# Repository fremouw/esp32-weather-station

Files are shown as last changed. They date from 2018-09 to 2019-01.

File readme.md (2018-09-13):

# ESP32 Weather Station

[ESP32](https://www.espressif.com/en/products/hardware/esp32/overview) based weather station. It shows four screens. 1) Current time and date (synced over NTP) 2) The current (local) weather conditions (data from the Weather underground) 3) 3-day forecast (also with data from the weather underground) 4) Current temperature, humidity, air pressure and, air quality (eCO2 and TVOC). This project was once based on https://github.com/squix78/esp8266-weather-station-platformio-demo, but most of it probably 90% is rewritten and targeted for the ESP32.

## Demo
(http://www.youtube.com/watch?v=XPXsWYJnScY "demo video")
## Software

Please see the config.example.h to configure your board.

## Hardware

My version uses a [2.42" OLED display](https://www.ebay.com/itm/SPI-2-42-OLED-128x64-Graphic-OLED-Module-Display-Arduino-PIC-AVR-Multi-wii/162156495387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) over SPI. A Bosch BME280 chip for measuring the temperature, humidity and air pressure. The SGP30 is used to measure the air quality, eCO2 (equivalent calculated carbon-dioxide) and TVOC (Total Volatile Organic Compound) concentration. Both these sensors are attached using a 4-wire molex connector, to keep some distance from the board and display; as these generate some heat which influences the sensors.

The ESP32 board used is a DOIT ESP32 Devkit v1, you can find these on ebay.

### Schematic and board

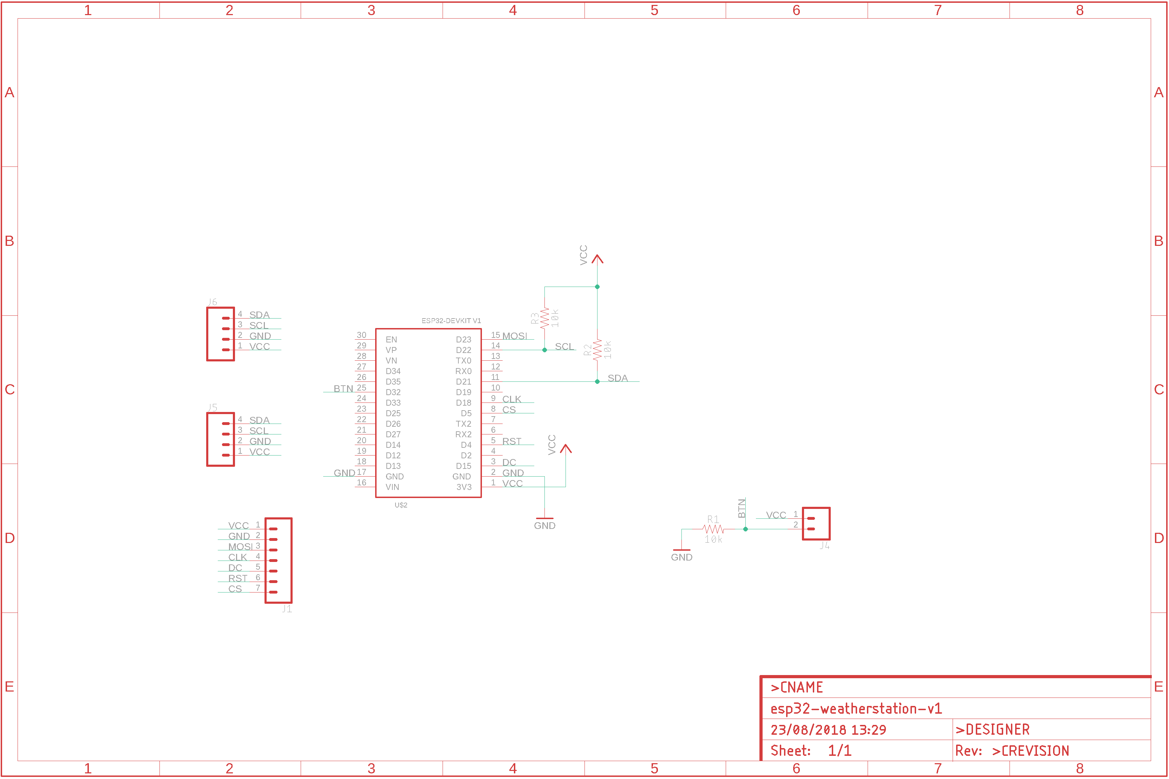
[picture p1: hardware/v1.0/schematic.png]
Schematic


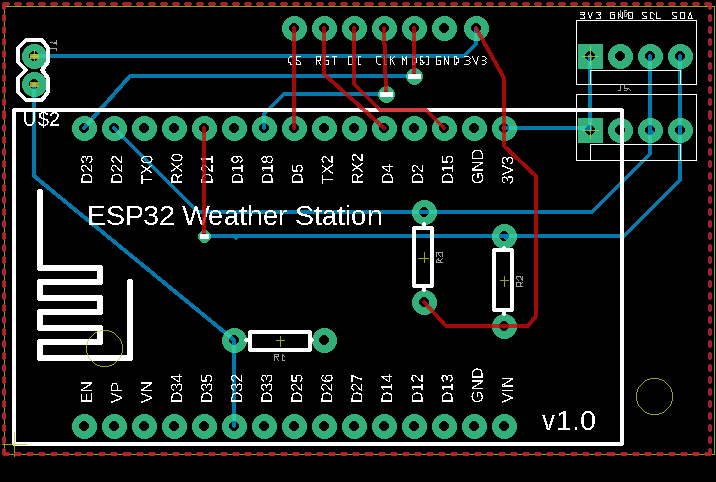
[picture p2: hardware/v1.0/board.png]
Board


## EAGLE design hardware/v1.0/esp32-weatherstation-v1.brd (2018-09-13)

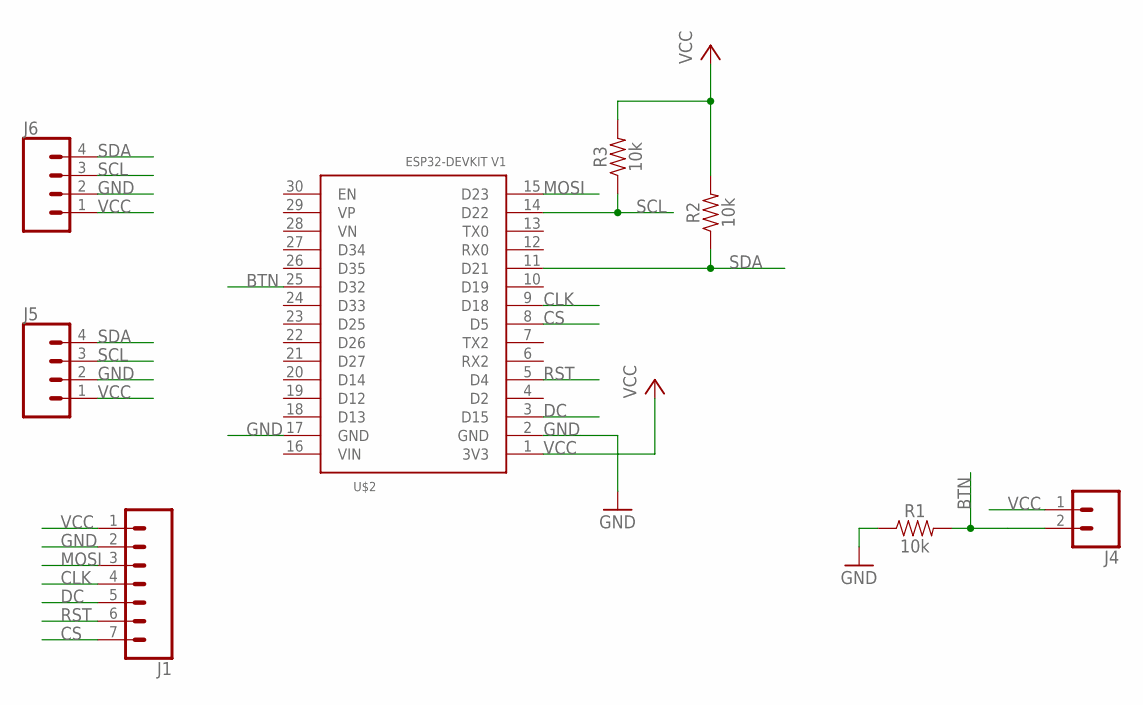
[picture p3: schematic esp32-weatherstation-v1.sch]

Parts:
J1: CONN_07; 1X07
J4: CONN_02; 1X02
J5, J6: CONN_04POLAR; MOLEX-1X4
R1, R2, R3: 10k; AXIAL-0.3
U$2: DOIT-ESP32DEVKIT1; ESP32-DEVKITV1

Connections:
BTN: J4.2, R1.P$2 (2), U$2.25 (D32)
CLK: J1.4, U$2.9 (D18)
CS: J1.7, U$2.8 (D5)
DC: J1.5, U$2.3 (D15)
GND: J1.2, J5.2, J6.2, R1.P$1 (1), U$2.2 (GND), U$2.17 (GND)
MOSI: J1.3, U$2.15 (D23)
RST: J1.6, U$2.5 (D4)
SCL: J5.3, J6.3, R3.P$1 (1), U$2.14 (D22)
SDA: J5.4, J6.4, R2.P$1 (1), U$2.11 (D21)
VCC: J1.1, J4.1, J5.1, J6.1, R2.P$2 (2), R3.P$2 (2), U$2.1 (3V3)

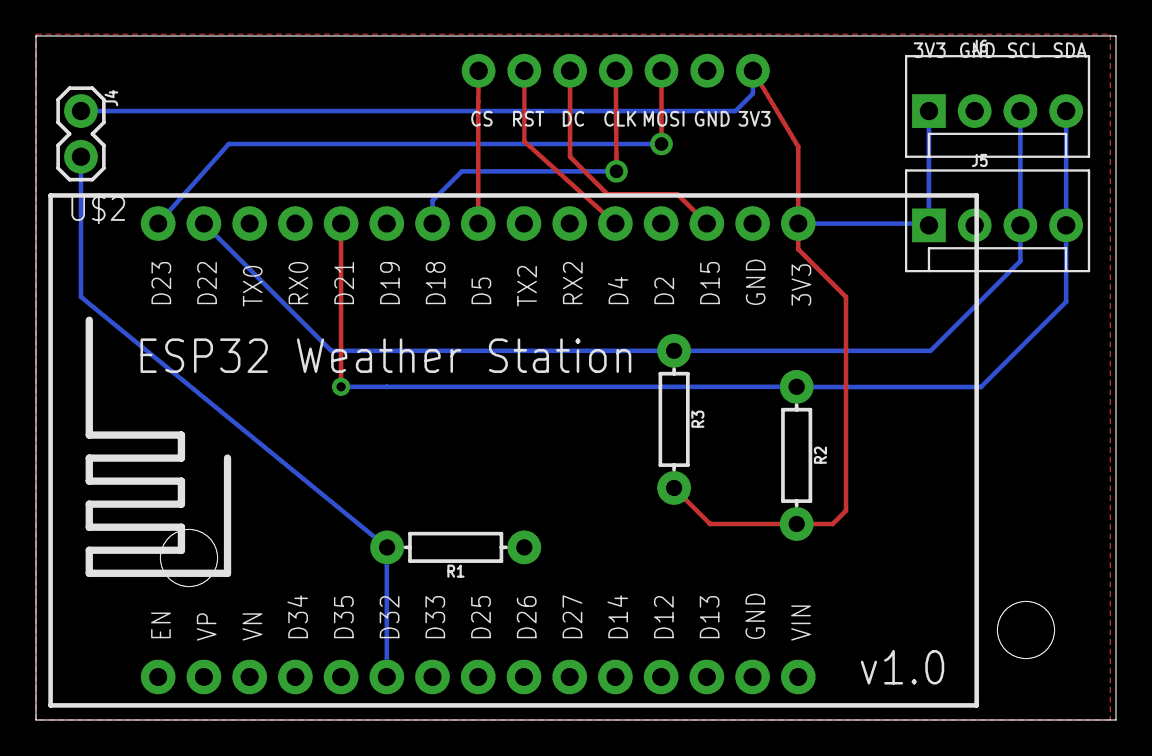
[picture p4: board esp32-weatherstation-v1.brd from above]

Board: 2 copper layers, 60.0 x 38.0 mm, 8 parts (1 on the bottom side), 10 nets.

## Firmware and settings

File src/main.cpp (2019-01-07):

#include <Arduino.h>
#include <WiFi.h>
#include <esp_log.h>
#include "config.h"
#include "weather_station.h"
#include "wireless/wifi_manager.h"

WiFiManager wifiManager;

WeatherStation weatherStation(wifiManager);

void setup() {
  // put your setup code here, to run once:
  Serial.begin(115200);

  Serial.print(F("\r\nBooting Weather Station v1.0-"));
  Serial.print(APP_VERSION);
  Serial.print(F(" ("));
  Serial.print(__TIMESTAMP__);
  Serial.println(F(")."));
  Serial.print(F("ESP32 SDK version is: "));
  Serial.print(ESP.getSdkVersion());
  Serial.println(F("."));
  Serial.print(F("CPU revision is: "));
  Serial.print(ESP.getChipRevision());
  Serial.println(F(""));
  Serial.print(F("Clocks: CPU="));
  Serial.print(ESP.getCpuFreqMHz());
  Serial.print(F(" MHz, Flash="));
  Serial.print(ESP.getFlashChipSpeed() / 1000000);
  Serial.println(F(" MHz"));
  Serial.print(F("Flash: Size="));
  Serial.print(ESP.getFlashChipSize());
  Serial.println(F(" bytes"));
  // Serial.print(F("Memory: Total="));
  // Serial.print(ESP.getHeapSize());
  Serial.println(F(" bytes"));
  Serial.print(F("Memory: Free="));
  Serial.print(ESP.getFreeHeap());
  Serial.println(F(" bytes"));

  weatherStation.setup();

  wifiManager.setup(WSConfig::kSsid, WSConfig::kSsidPassword);
}

void loop() {
  static bool printRunningCore = false;
  if(!printRunningCore) {
    printRunningCore = true;
    Serial.print(F("Arduino running core: "));
    Serial.println(xPortGetCoreID());
  }

  weatherStation.loop();
}

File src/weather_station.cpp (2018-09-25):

#include "weather_station.h"
#include "tools/timer.h"
#include "config.h"
#include <esp_log.h>

volatile SemaphoreHandle_t WeatherStation::SuperShortIntervalTimerSemaphore = xSemaphoreCreateBinary();
volatile SemaphoreHandle_t WeatherStation::ShortIntervalTimerSemaphore = xSemaphoreCreateBinary();
volatile SemaphoreHandle_t WeatherStation::MediumIntervalTimerSemaphore = xSemaphoreCreateBinary();
volatile SemaphoreHandle_t WeatherStation::LongIntervalTimerSemaphore = xSemaphoreCreateBinary();

const char WeatherStation::kTVOCKey[] PROGMEM = "ws.aq.tvoc";
const char WeatherStation::kECO2Key[] PROGMEM = "ws.aq.eco2";

static const char LogTag[] PROGMEM = "WeatherStation";

WeatherStation::WeatherStation(WiFiManager& wifiManager)
  : w0(0)
    , spi(VSPI)
    , mqttPublisher(wifiClient)
    , wifiManager(wifiManager)
    , display(WSConfig::kSpiResetPin, WSConfig::kSpiDcPin, WSConfig::kSpiCsPin, spi)
    , weatherDisplay(display, ntpClient, conditions, environmentMeasurement, airQualityMeasurement)
    , wunderground(WSConfig::kWundergroundApiKey, WSConfig::kWundergroundLanguage, WSConfig::kWundergroundLocation)
    , environmentSensor(w0)
    , airQualitySensor(w0) {}

WeatherStation::~WeatherStation() {}

void WeatherStation::setup() {
  this->w0.begin(WSConfig::kI2cSdaPin, WSConfig::kI2cSclPin, 400000);

  this->mqttPublisher.setup(WSConfig::kMqttBroker,
    WSConfig::kMqttBrokerPort,
    WSConfig::kMqttBrokerUsername,
    WSConfig::kMqttBrokerPassword);

  this->environmentSensor.setup();
  this->airQualitySensor.setup();

  this->wifiManager.onConnected(std::bind(&WeatherStation::onConnectedToWireless, this));

  this->weatherDisplay.setup();

  this->ntpClient.setup(WSConfig::kNtpServerName);

  this->store.loadConfig();

  Sensors::AirQuality::Measurement aqBaselineMeasurement = { 0, 0 };
  this->store.get(kTVOCKey, aqBaselineMeasurement.tVoc);
  this->store.get(kECO2Key, aqBaselineMeasurement.eCo2);

  if(aqBaselineMeasurement.eCo2 > 0 && aqBaselineMeasurement.tVoc > 0) {
    ESP_LOGI(LogTask, "air quality baseline from EEPROM: eCO2=0x%02X ppm, TVOC=0x%02X ppb", aqBaselineMeasurement.eCo2, aqBaselineMeasurement.tVoc);

    this->airQualitySensor.setBaseline(aqBaselineMeasurement);
  }

  static const char kBackgroundTaskName[] PROGMEM = "WeatherStation::StaticBackgroundTask";

  xTaskCreatePinnedToCore(
    WeatherStation::StaticDisplayTask,      /* Task function. */
    kBackgroundTaskName,                    /* name of task. */
    8192,                                   /* Stack size of task */
    this,                                   /* parameter of the task */
    4,                                      /* priority of the task */
    NULL,                                   /* Task handle to keep track of created task */
    0);                                     /* pin task to core 0 */

  this->superShortUpdateTimer = Timer::CreateTimer(&WeatherStation::OnSuperShortIntervalTimer, 3, 10000000, true, 80);
  this->shortUpdateTimer = Timer::CreateTimer(&WeatherStation::OnShortIntervalTimer, 0, 60000000, true, 80);
  this->mediumUpdateTimer = Timer::CreateTimer(&WeatherStation::OnMediumIntervalTimer, 1, 300000000, true, 80);
  this->longUpdateTimer = Timer::CreateTimer(&WeatherStation::OnLongIntervalTimer, 2, 3600000000, true, 80);

  this->tasks = WeatherStationTasks::eIdle;

  // Max frequence of OLED display.
  spi.setFrequency(10000000);
}

void WeatherStation::onConnectedToWireless() {
  Serial.println(F("info: weather station: got interwebz!"));

  // Force updating just everything :-)
  this->tasks = WeatherStationTasks::eUpdateDateAndTime
    | WeatherStationTasks::eUpdateWeatherReport
    | WeatherStationTasks::eUpdateEnvironmentSensor
    | WeatherStationTasks::eUpdateAirQualitySensor
    | WeatherStationTasks::ePushTemperature;
}

void WeatherStation::loop() {
  this->wifiManager.loop();

  int8_t wiFiQuality = 0;
  WiFiManager::GetWifiQuality(wiFiQuality);

  this->weatherDisplay.setWifiQuality(wiFiQuality);

  if (xSemaphoreTake(WeatherStation::SuperShortIntervalTimerSemaphore, 0) == pdTRUE) {
    // ESP_LOGI(LogTag, "super short timer fired, running on core %d.", xPortGetCoreID());

    this->tasks |= WeatherStationTasks::eUpdateEnvironmentSensor;
    this->tasks |= WeatherStationTasks::eUpdateAirQualitySensor;
  }

  if (xSemaphoreTake(WeatherStation::ShortIntervalTimerSemaphore, 0) == pdTRUE) {
    // ESP_LOGI(LogTag, "short timer fired, running on core %d.", xPortGetCoreID());

    ESP_LOGI(LogTag, "free heap: %d bytes.", ESP.getFreeHeap());

    this->tasks |= WeatherStationTasks::ePushTemperature;
  }

  if (xSemaphoreTake(WeatherStation::MediumIntervalTimerSemaphore, 0) == pdTRUE) {
    // ESP_LOGI(LogTag, "timer fired, running on core %d,", xPortGetCoreID());

    this->tasks |= WeatherStationTasks::eUpdateWeatherReport;
  }

  if (xSemaphoreTake(WeatherStation::LongIntervalTimerSemaphore, 0) == pdTRUE) {
    ESP_LOGI(LogTag, "slow timer fired, running on core %d.", xPortGetCoreID());

    this->tasks |= WeatherStationTasks::eUpdateDateAndTime;
  }

  if(this->tasks & WeatherStationTasks::eUpdateEnvironmentSensor) {
    this->tasks &= ~WeatherStationTasks::eUpdateEnvironmentSensor;

    Sensors::Environment::Measurement measurement;

    // If it didn't succeed, show last temperature.
    bool success = this->environmentSensor.measure(measurement);
    if(success) {
      this->environmentMeasurement = measurement;

      Serial.print(F("weather station: read environmental sensor: temperature="));
      Serial.print(this->environmentMeasurement.temperature);
      Serial.print(F(" pressure="));
      Serial.print(this->environmentMeasurement.pressure);
      Serial.print(F(" humidity="));
      Serial.println(this->environmentMeasurement.humidity);

      // Improves quality of CO2 measurement.
      this->airQualitySensor.setHumidity(this->environmentMeasurement.humidity);
      this->weatherDisplay.addFrame(Frames::eIndoorSensors);
    }
  }

  if(this->tasks & WeatherStationTasks::eUpdateAirQualitySensor) {
    this->tasks &= ~WeatherStationTasks::eUpdateAirQualitySensor;

    Sensors::AirQuality::Measurement airQualityMeasurement;
    bool success = this->airQualitySensor.measure(airQualityMeasurement);
    if(success) {
      this->airQualityMeasurement = airQualityMeasurement;

      Serial.print(F("weather station: read airquality sensor: eCO2="));
      Serial.print(this->airQualityMeasurement.eCo2);
      Serial.print(F(" ppm TVOC="));
      Serial.print(this->airQualityMeasurement.tVoc);
      Serial.println(F(" ppb"));
    }
  }

  if(!this->wifiManager.isConnected()) {
    delay(1000);

    return;
  }

  this->mqttPublisher.loop();

  if(this->tasks & WeatherStationTasks::eUpdateDateAndTime) {
    this->tasks &= ~WeatherStationTasks::eUpdateDateAndTime;

    ESP_LOGI(LogTag, "updating date and time (%d) on core %d...", this->tasks, xPortGetCoreID());
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

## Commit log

2018-02-20 use multiple i2c busses, until timeouts are resolved with two devices on one bus.
    [config.example.h, main.cpp, weather_station.cpp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]
2018-02-21 fix: return current unixtime.
2018-02-21 pushing temperature/humidity/pressure to mqtt broker is optional.
    [config.example.h, weather_station.cpp, weather_station.h]
2018-02-21 check if temperature was actually read.
2018-02-21 add timeout to temperature measurement.
2018-02-22 set i2c bus for bme280 to 100kHz
2018-02-23 use delta of last and current temperature measurement to check if the reading makes sense.
2018-04-05 SPI + SGP30 test.
2018-08-18 working with spi.
2018-08-19 add air quality sensor
2018-08-19 since we run the display now over SPI, we can move the sensor reading to the background task.
2018-08-19 switch to new commit of SGP lib.
2018-08-19 move sensor readings to main loop, seems to generate errors when running on 2nd cpu.
    [weather_station.cpp]
2018-08-21 Store the baseline of the air quality sensor in the EEPROM after pressing a button.
2018-09-13 added schematics and board.
    [esp32-weatherstation-v1.brd, esp32-weatherstation-v1.sch]
2018-09-13 added missing config option.
    [config.example.h]
2018-09-13 added screens of schematic and board.
2018-09-14 Only show log line when there's data to push to the broker.
    [weather_station.cpp]
2018-09-25 round temperatures in 3 day forecast to integers.
2019-01-07 switch to stable espressif32 platform.

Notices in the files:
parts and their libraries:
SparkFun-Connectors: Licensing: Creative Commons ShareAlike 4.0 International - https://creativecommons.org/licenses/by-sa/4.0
